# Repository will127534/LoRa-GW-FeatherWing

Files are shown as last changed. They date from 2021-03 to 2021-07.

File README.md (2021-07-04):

# LoRa Gateway FeatherWing

## Description
This is a LoRa Gateway board designed for FeatherWing ecosystem, based on Semtech SX1303 Digital Baseband Chip and Ublox EVA-7M GPS module. Board schematic is largely based on the SX1303 reference design, and this board is designed for 915Mhz operation.


**This Design is still in development process, please use with caution**  

**MCU software is also in development process**  
You can find it here https://github.com/will127534/SX1302_Arduino_Library

## FeatherWing Connection usage
SX1303 uses the SPI bus and two GPIO (CS and Reset on D5 and D6) on the FeatherWing to communicate with host MCU  
GPS module uses the UART pins and a GPIO for pulse-per-second output on A5.  

## Design Tool
KiCad v5.99 is used to design the board, and JLCPCB to manufactured the board.


I'm pretty noob about the KiCad stuff, so any feedback is welcome.

## Parts sourcing
I sourced most parts from Mouser, here is the parts list:
https://www.mouser.com/ProjectManager/ProjectDetail.aspx?AccessID=11549c8008

Note: SMA connector is not included, because it is related to the board thickness your are using, I'm using 1mm 4 layer pcb, and I can't find the connector on Mouser.

CC BY-SA 4.0

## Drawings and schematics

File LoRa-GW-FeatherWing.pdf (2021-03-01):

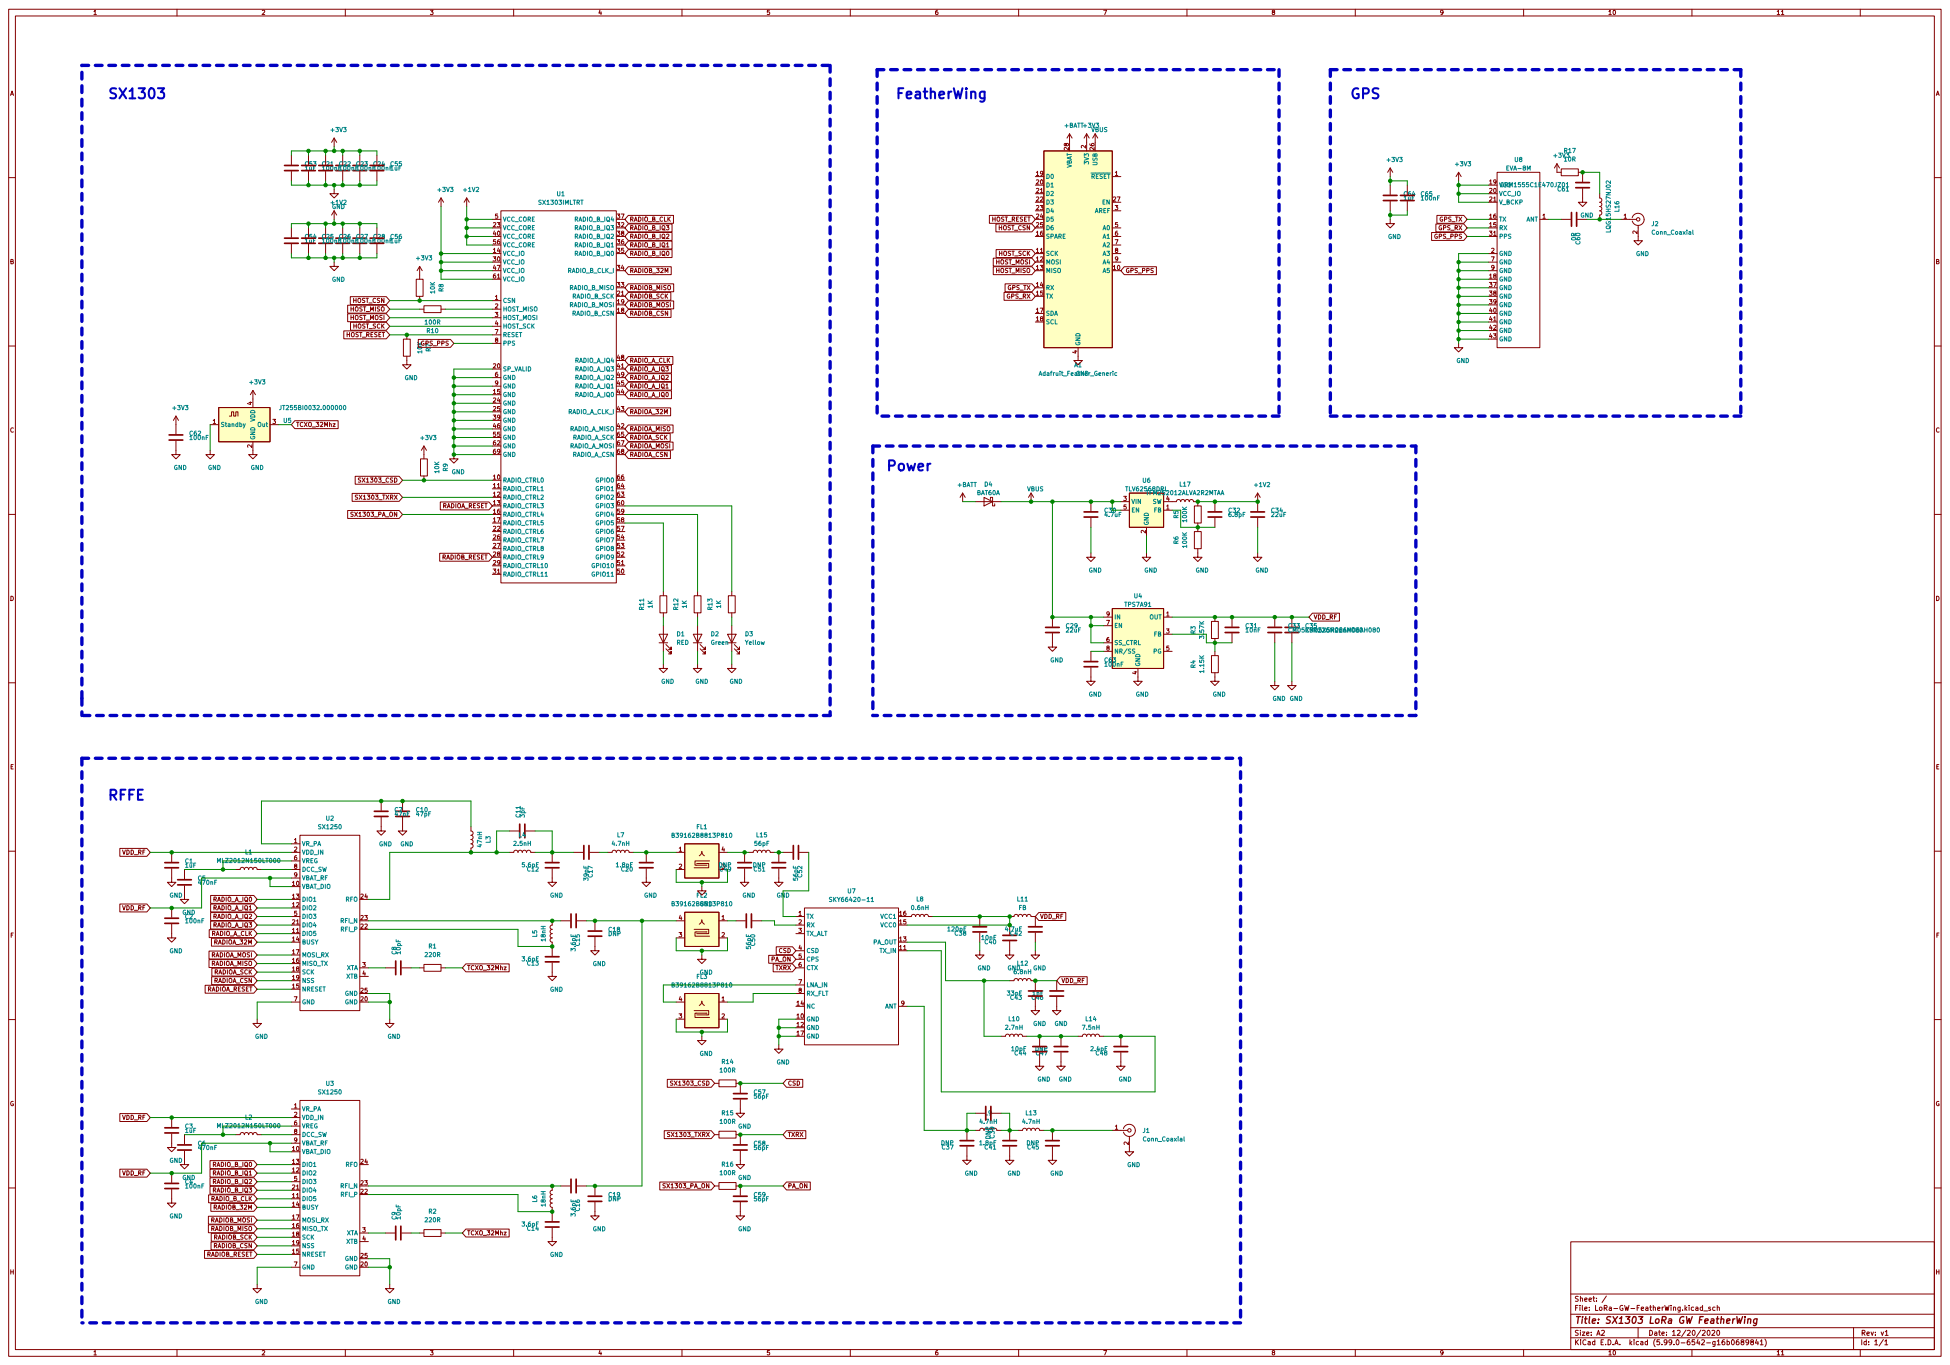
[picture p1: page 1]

2 D1 20 D2 21 D3 22 D4 23 D5 24 D6 25 USB 26 EN 27 VBAT 28 AREF 3 GND

File: LoRa-GW-FeatherWing.kicad_sch Sheet: /
Id: 1/1 Title: SX1303 LoRa GW FeatherWing

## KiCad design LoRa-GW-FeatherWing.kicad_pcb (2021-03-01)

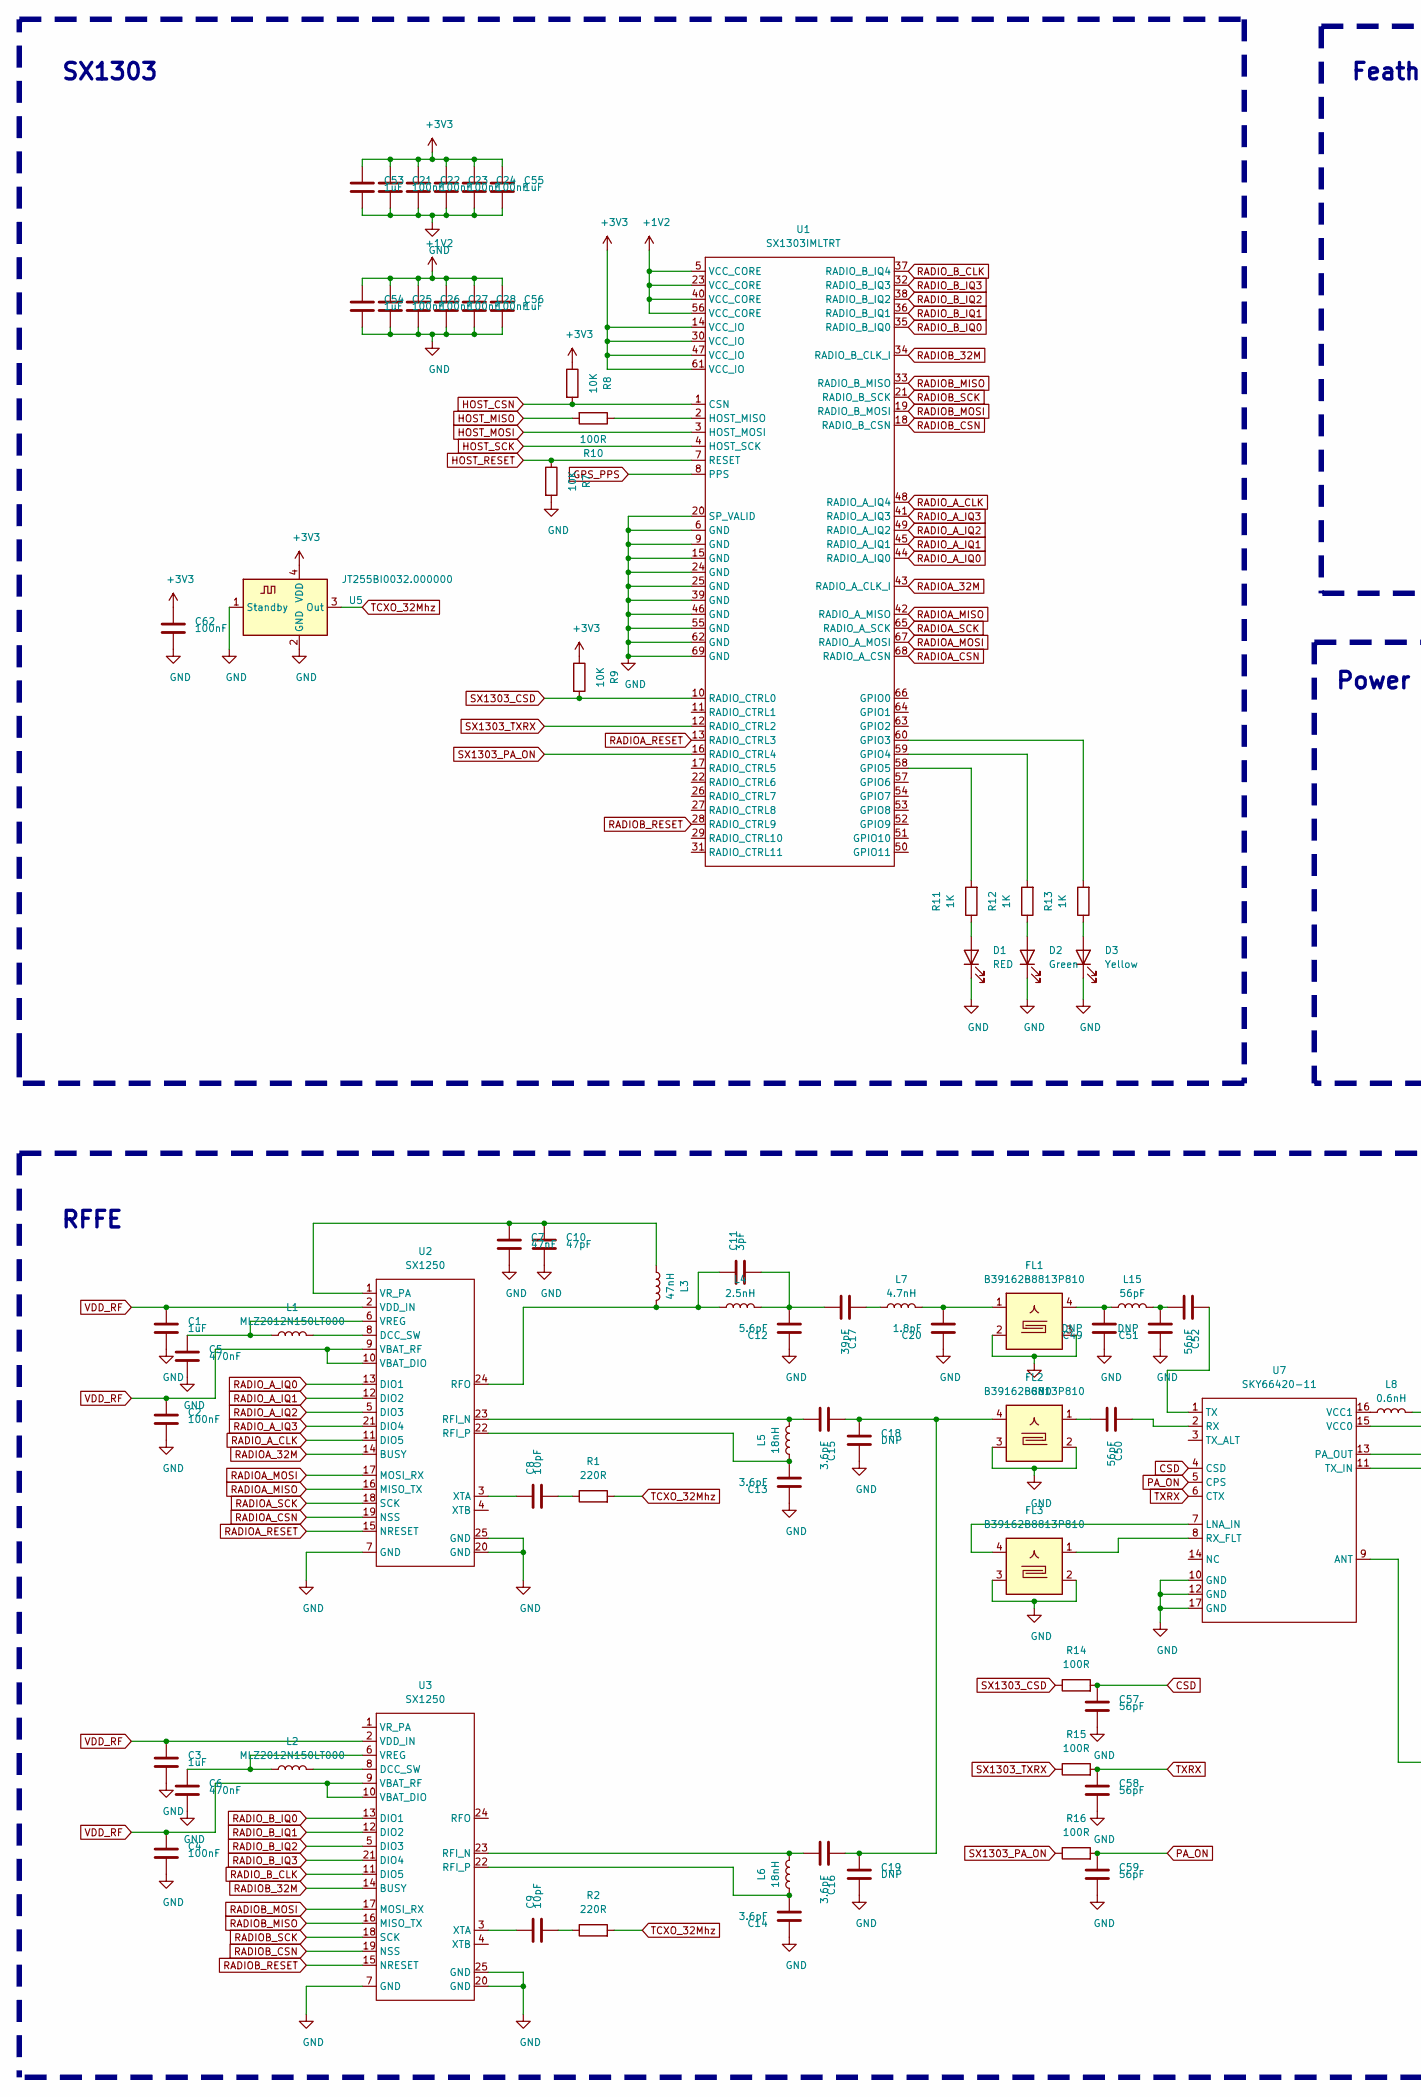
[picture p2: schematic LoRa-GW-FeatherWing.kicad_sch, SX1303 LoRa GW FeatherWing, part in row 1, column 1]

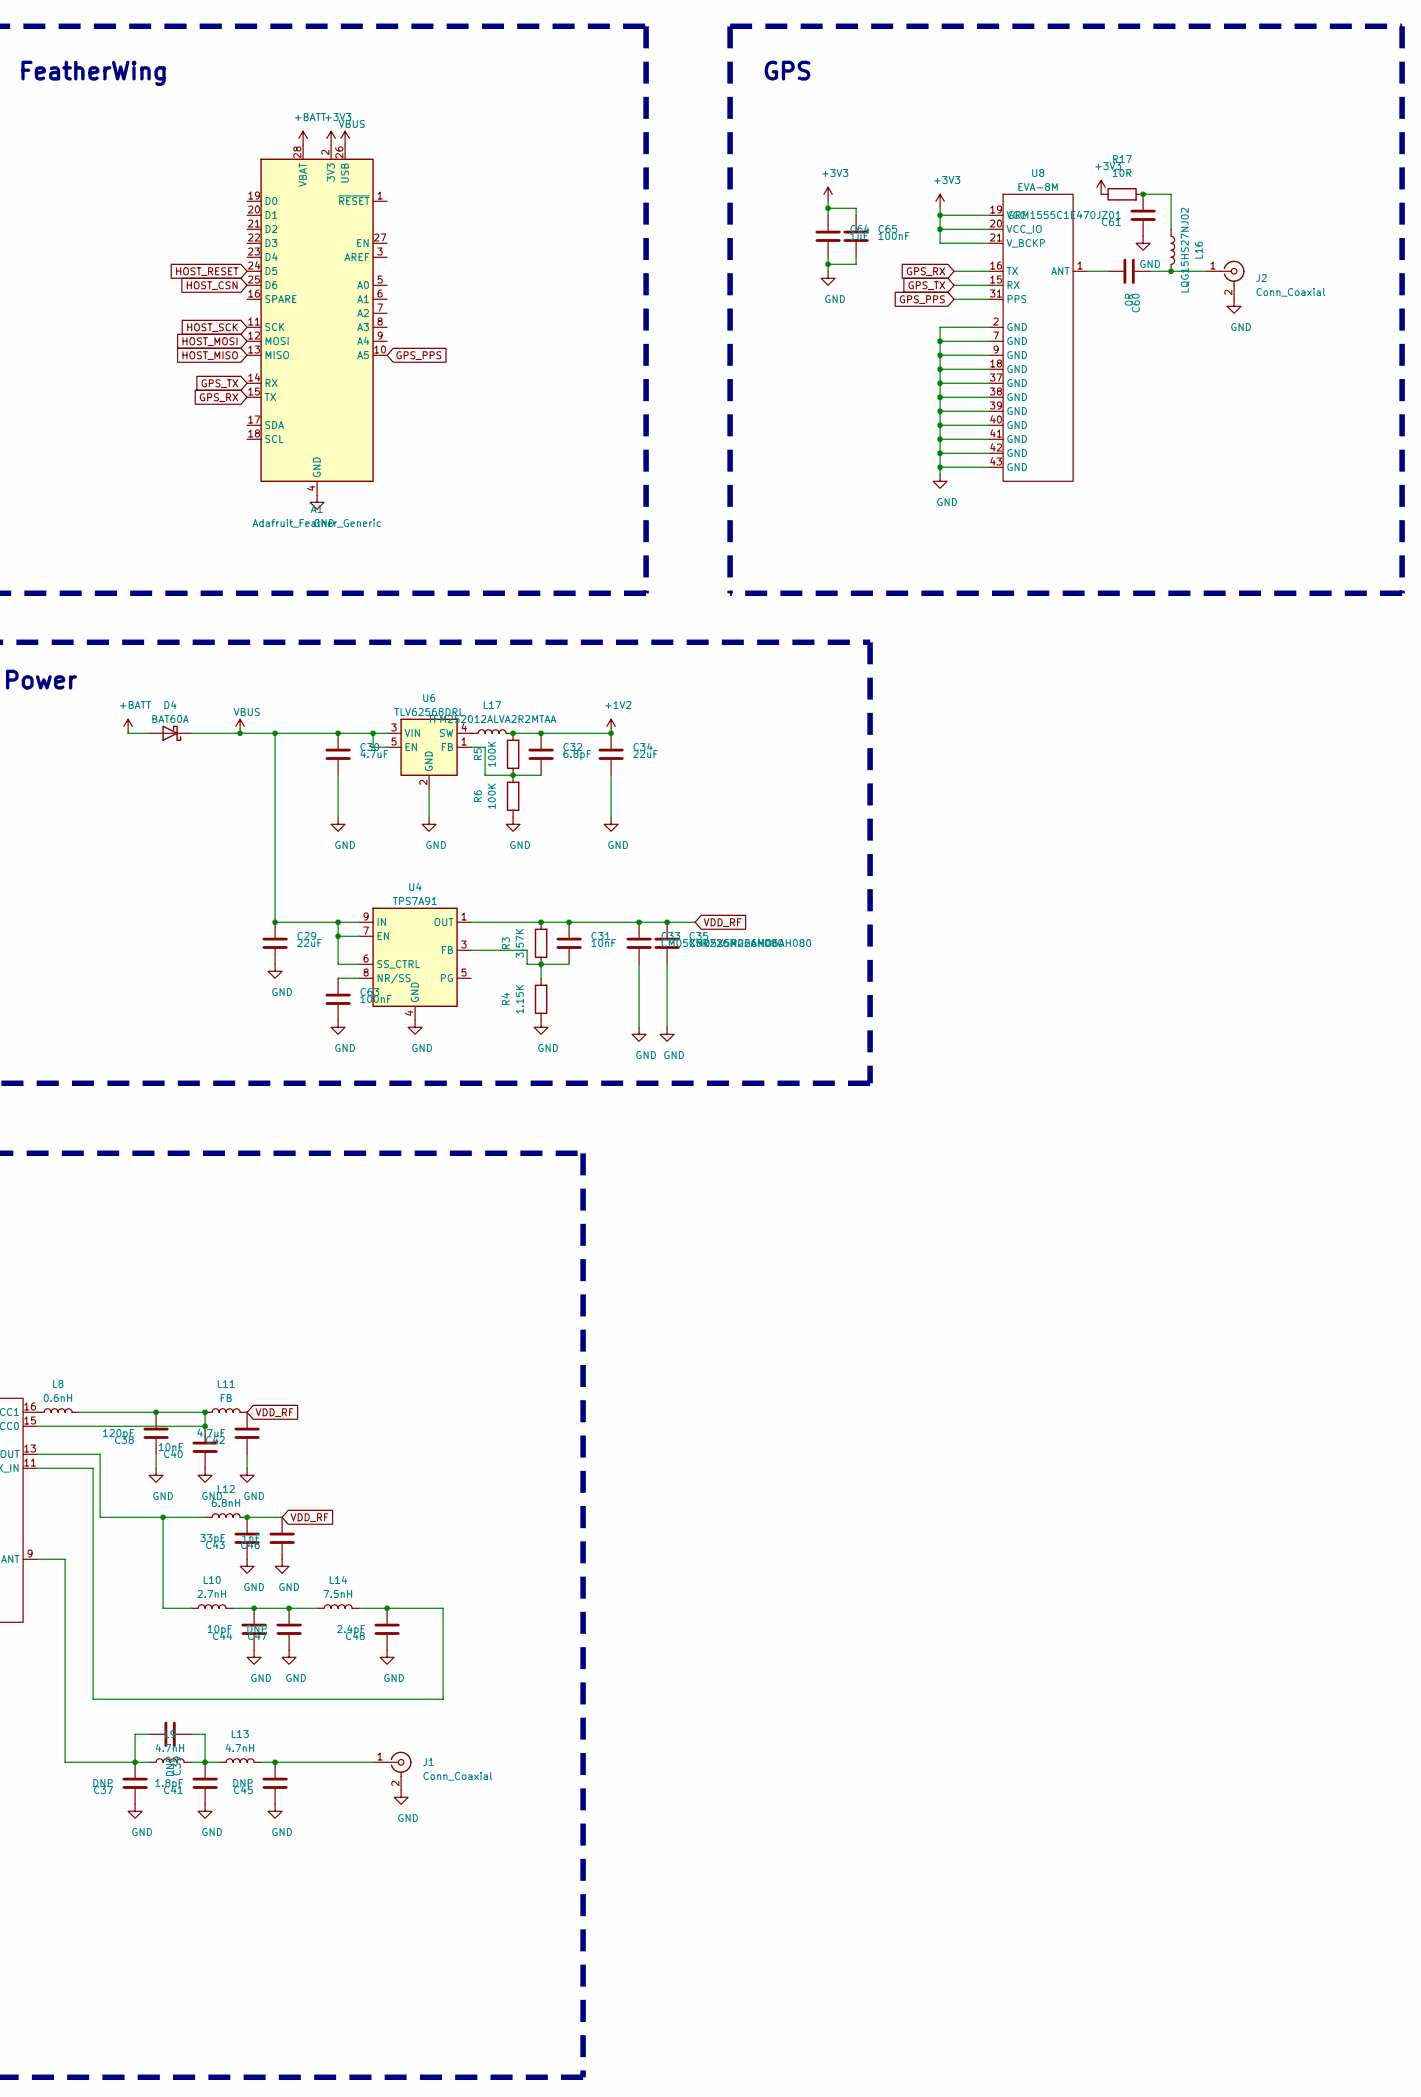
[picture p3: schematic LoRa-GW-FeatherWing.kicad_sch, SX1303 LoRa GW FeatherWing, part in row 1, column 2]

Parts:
A1: Adafruit_Feather_Generic; Adafruit_Feather
C1, C3, C64: 1uF; C_0402_1005Metric
C2, C4, C65: 100nF; C_0402_1005Metric
C5, C6: 470nF; C_0402_1005Metric
C7: 47nF; C_0402_1005Metric
C8, C9, C44: 10pF; C_0201_0603Metric
C10: 47pF; C_0402_1005Metric
C11: 3pF; C_0201_0603Metric
C12: 5.6pF; C_0201_0603Metric
C13, C14, C15, C16: 3.6pF; C_0201_0603Metric
C17: 39pF; C_0201_0603Metric
C18, C19, C37, C39, C45, C47, C49, C51: DNP; C_0201_0603Metric
C20, C41: 1.8pF; C_0201_0603Metric
C21, C22, C23, C24, C25, C26, C27, C28, C62, C63: 100nF; C_0201_0603Metric
C29: 22uF; C_0402_1005Metric
C30, C42: 4.7uF; C_0402_1005Metric
C31: 10nF; C_0402_1005Metric
C32: 6.8pF; C_0402_1005Metric
C33, C35: CM05X5R226M06AH080; C_0402_1005Metric
C34: 22uF; C_0603_1608Metric
C38: 120pF; C_0201_0603Metric
C40: 10nF; C_0201_0603Metric
C43: 33pF; C_0201_0603Metric
C46: 1nF; C_0201_0603Metric
C48: 2.4pF; C_0201_0603Metric
C50, C52, C57, C58, C59: 56pF; C_0201_0603Metric
C53, C54, C55, C56: 1uF; C_0201_0603Metric
C60: 0R; C_0201_0603Metric
C61: GRM1555C1E470JZ01; C_0201_0603Metric
D1: RED; LED_0603_1608Metric
D2: Green; LED_0603_1608Metric
D3: Yellow; LED_0603_1608Metric
D4: BAT60A; D_SOD-323
FL1, FL2, FL3: B39162B8813P810; Filter_1109-5_1.1x0.9mm
J1: Conn_Coaxial; SMA_Samtec_SMA-J-P-X-ST-EM1_EdgeMount
J2: Conn_Coaxial; U.FL_Hirose_U.FL-R-SMT-1_Vertical
L1, L2: MLZ2012N150LT000; L_0805_2012Metric
L3: 47nH; L_0201_0603Metric
L4: 2.5nH; L_0201_0603Metric
L5, L6: 18nH; L_0201_0603Metric
L7, L9, L13: 4.7nH; L_0201_0603Metric
L8: 0.6nH; L_0201_0603Metric
L10: 2.7nH; L_0201_0603Metric
L11: FB; L_0201_0603Metric
L12: 6.8nH; L_0201_0603Metric
L14: 7.5nH; L_0201_0603Metric
L15: 56pF; L_0201_0603Metric
L16: LQG15HS27NJ02; L_0201_0603Metric
L17: TFM252012ALVA2R2MTAA; L_1008_2520Metric
R1, R2: 220R; R_0201_0603Metric
R3: 3.57K; R_0402_1005Metric
R4: 1.15K; R_0402_1005Metric
R5, R6: 100K; R_0402_1005Metric
R7, R8, R9: 10K; R_0201_0603Metric
R10, R14, R15, R16: 100R; R_0201_0603Metric
R11, R12, R13: 1K; R_0402_1005Metric
R17: 10R; R_0402_1005Metric
U1: SX1303IMLTRT; SX1302IMLTRT
U2, U3: SX1250; HVQFN-24-1EP_4x4mm_P0.5mm_EP2.5x2.5mm
U4: TPS7A91; Texas_S-PDSO-N10_EP1.2x2mm
U5: JT255BI0032.000000; Oscillator_SMD_Abracon_ASDMB-4Pin_2.5x2.0mm
U6: TLV62568DRL; SOT-563
U7: SKY66420-11; QFN-16-1EP_3x3mm_P0.5mm_EP1.75x1.75mm
U8: EVA-8M

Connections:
+1V2: C25.1, C26.1, C27.1, C28.1, C32.1, C34.1, C54.1, C56.1, L17.2, R5.2, U1.5 (VCC_CORE), U1.23 (VCC_CORE), U1.40 (VCC_CORE), U1.56 (VCC_CORE)
+3V3: A1.2 (3V3), C21.1, C22.1, C23.1, C24.1, C53.1, C55.1, C62.1, C64.1, C65.1, R8.1, R9.1, R17.1, U1.14 (VCC_IO), U1.30 (VCC_IO), U1.47 (VCC_IO), U1.61 (VCC_IO), U5.4 (VDD), U8.19 (VCC), U8.20 (VCC_IO), U8.21 (V_BCKP)
+BATT: A1.28 (VBAT), D4.2 (A)
CSD: C57.1, R14.2, U7.4 (CSD)
GND: A1.4 (GND), C1.2, C2.2, C3.2, C4.2, C5.2, C6.2, C7.2, C10.2, C12.1, C13.1, C14.1, C18.2, C19.2, C20.1, C21.2, C22.2, C23.2, C24.2, C25.2, C26.2, C27.2, C28.2, C29.2, C30.2, C33.2, C34.2, C35.2, C37.1, C38.1, C40.1, C41.1, C42.1, C43.1, C44.1, C45.1, C46.1, C47.1, C48.1, C49.1, C51.1, C53.2, C54.2, C55.2, C56.2, C57.2, C58.2, C59.2, C61.1, C62.2, C63.2, C64.2, C65.2, D1.1 (K), D2.1 (K), D3.1 (K), FL1.2, FL1.3, FL1.5, FL2.2, FL2.3, FL2.5, FL3.2, FL3.3, FL3.5, J1.2 (Ext), J2.2 (Ext), R4.1, R6.1, R7.2, U1.6 (GND), U1.9 (GND), U1.15 (GND), U1.20 (SP_VALID), U1.24 (GND), U1.25 (GND), U1.39 (GND), U1.46 (GND), U1.55 (GND), U1.62 (GND), U1.69 (GND), U2.7 (GND), U2.20 (GND), U2.25 (GND), U3.7 (GND), U3.20 (GND), U3.25 (GND), U4.4 (GND), U4.11 (GND), U5.1 (Standby), U5.2 (GND), U6.2 (GND), U7.10 (GND), U7.12 (GND), U7.17 (GND), U8.2 (GND), U8.7 (GND), U8.9 (GND), U8.18 (GND), U8.37 (GND), U8.38 (GND), U8.39 (GND), U8.40 (GND), U8.41 (GND), U8.42 (GND), U8.43 (GND)
GPS_PPS: A1.10 (A5), U1.8 (PPS), U8.31 (PPS)
HOST_CSN: A1.25 (D6), R8.2, U1.1 (CSN)
HOST_MISO: A1.13 (MISO), R10.2
HOST_MOSI: A1.12 (MOSI), U1.3 (HOST_MOSI)
HOST_RESET: A1.24 (D5), R7.1, U1.7 (RESET)
HOST_SCK: A1.11 (SCK), U1.4 (HOST_SCK)
unnamed: C5.1, L1.1, U2.6 (VREG)
unnamed: C6.1, L2.1, U3.6 (VREG)
unnamed: C8.1, U2.3 (XTA)
unnamed: C8.2, R1.1
unnamed: C9.1, U3.3 (XTA)
unnamed: C9.2, R2.1
unnamed: C7.1, C10.1, L3.1, U2.1 (VR_PA)
unnamed: C11.1, L3.2, L4.1, U2.24 (RFO)
unnamed: C11.2, C12.2, C17.2, L4.2
unnamed: C13.2, L5.1, U2.22 (RFI_P)
unnamed: C14.2, L6.1, U3.22 (RFI_P)
unnamed: C15.1, C16.1, C18.1, C19.1, FL2.4
unnamed: C15.2, L5.2, U2.23 (RFI_N)
unnamed: C16.2, L6.2, U3.23 (RFI_N)
unnamed: C17.1, L7.1
unnamed: C20.2, FL1.1, L7.2
unnamed: C31.2, R3.1, R4.2, U4.3 (FB)
unnamed: C32.2, R5.1, R6.2, U6.1 (FB)
unnamed: C37.2, C39.2, L9.1, U7.9 (ANT)
unnamed: C38.2, C40.2, L8.2, L11.1, U7.15 (VCC0)
unnamed: C39.1, C41.2, L9.2, L13.1
unnamed: C44.2, C47.2, L10.2, L14.1
unnamed: C45.2, J1.1 (In), L13.2
unnamed: C48.2, L14.2, U7.11 (TX_IN)
unnamed: C49.2, FL1.4, L15.1
unnamed: C50.1, U7.2 (RX)
unnamed: C50.2, FL2.1
unnamed: C51.2, C52.2, L15.2
unnamed: C52.1, U7.1 (TX)
unnamed: C60.1, J2.1 (In), L16.2
unnamed: C60.2, U8.1 (ANT)
unnamed: C61.2, L16.1, R17.2
unnamed: C63.1, U4.8 (NR/SS)
unnamed: D1.2 (A), R11.1
unnamed: D2.2 (A), R12.1
unnamed: D3.2 (A), R13.1
unnamed: FL3.1, U7.8 (RX_FLT)
unnamed: FL3.4, U7.7 (LNA_IN)
unnamed: L1.2, U2.8 (DCC_SW)
unnamed: L2.2, U3.8 (DCC_SW)
unnamed: L8.1, U7.16 (VCC1)
unnamed: L10.1, L12.1, U7.13 (PA_OUT)
unnamed: L17.1, U6.4 (SW)
unnamed: R10.1, U1.2 (HOST_MISO)
unnamed: R11.2, U1.58 (GPIO5)
unnamed: R12.2, U1.59 (GPIO4)
unnamed: R13.2, U1.60 (GPIO3)
PA_ON: C59.1, R16.2, U7.5 (CPS)
RADIOA_32M: U1.43 (RADIO_A_CLK_I), U2.14 (BUSY)
RADIOA_CSN: U1.68 (RADIO_A_CSN), U2.19 (NSS)
RADIOA_MISO: U1.42 (RADIO_A_MISO), U2.16 (MISO_TX)
RADIOA_MOSI: U1.67 (RADIO_A_MOSI), U2.17 (MOSI_RX)
RADIOA_RESET: U1.13 (RADIO_CTRL3), U2.15 (NRESET)
RADIOA_SCK: U1.65 (RADIO_A_SCK), U2.18 (SCK)
RADIOB_32M: U1.34 (RADIO_B_CLK_I), U3.14 (BUSY)
RADIOB_CSN: U1.18 (RADIO_B_CSN), U3.19 (NSS)
RADIOB_MISO: U1.33 (RADIO_B_MISO), U3.16 (MISO_TX)
RADIOB_MOSI: U1.19 (RADIO_B_MOSI), U3.17 (MOSI_RX)
RADIOB_RESET: U1.28 (RADIO_CTRL9), U3.15 (NRESET)
RADIOB_SCK: U1.21 (RADIO_B_SCK), U3.18 (SCK)
RADIO_A_CLK: U1.48 (RADIO_A_IQ4), U2.11 (DIO5)
RADIO_A_IQ0: U1.44 (RADIO_A_IQ0), U2.13 (DIO1)
RADIO_A_IQ1: U1.45 (RADIO_A_IQ1), U2.12 (DIO2)
RADIO_A_IQ2: U1.49 (RADIO_A_IQ2), U2.5 (DIO3)
RADIO_A_IQ3: U1.41 (RADIO_A_IQ3), U2.21 (DIO4)
RADIO_B_CLK: U1.37 (RADIO_B_IQ4), U3.11 (DIO5)
RADIO_B_IQ0: U1.35 (RADIO_B_IQ0), U3.13 (DIO1)
RADIO_B_IQ1: U1.36 (RADIO_B_IQ1), U3.12 (DIO2)
RADIO_B_IQ2: U1.38 (RADIO_B_IQ2), U3.5 (DIO3)
RADIO_B_IQ3: U1.32 (RADIO_B_IQ3), U3.21 (DIO4)
SX1303_CSD: R9.2, R14.1, U1.10 (RADIO_CTRL0)
SX1303_PA_ON: R16.1, U1.16 (RADIO_CTRL4)
SX1303_TXRX: R15.1, U1.12 (RADIO_CTRL2)
TCXO_32Mhz: R1.2, R2.2, U5.3 (Out)
TXRX: C58.1, R15.2, U7.6 (CTX)
VBUS: A1.26 (USB), C29.1, C30.1, D4.1 (K), U4.6 (SS_CTRL), U4.7 (EN), U4.9 (IN), U4.10 (IN), U6.3 (VIN), U6.5 (EN)
VDD_RF: C1.1, C2.1, C3.1, C4.1, C31.1, C33.1, C35.1, C42.2, C43.2, C46.2, L11.2, L12.2, R3.2, U2.2 (VDD_IN), U2.9 (VBAT_RF), U2.10 (VBAT_DIO), U3.2 (VDD_IN), U3.9 (VBAT_RF), U3.10 (VBAT_DIO), U4.1 (OUT), U4.2 (OUT)

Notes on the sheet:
RFFE
SX1303
Power
FeatherWing
GPS

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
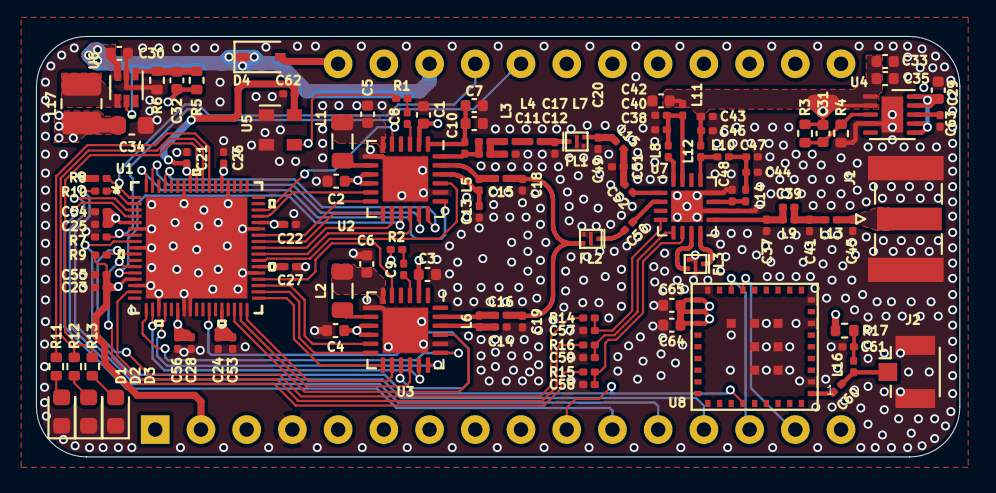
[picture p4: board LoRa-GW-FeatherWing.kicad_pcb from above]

Board: 4 copper layers, 51.3 x 23.4 mm, 116 parts (0 on the bottom side), 90 nets.

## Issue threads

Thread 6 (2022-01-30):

Understanding the RF FE

0y8w1x, 2022-01-30:
Hey, great project. I'm trying to build a LoRa gateway myself now. Can you please explain the FE architecture you use ?
I understand that the SKY66420 interfaces the antenna for both receiving and transmitting.

I don't understand the use of 2 SX1250. My guess would be that you can use both for receiving, so that would be 8x8 channels. And then sometimes you use 1 for transmitting ?

Also, I saw a picture on the forum, that you used an additional SX1262. That just adds to the confusion. What's the purpose of this transceiver in the chain ?

Appreciate your effort.

will127534, 2022-02-01:
You might want to take a look at SX1302 datasheet: [https://www.semtech.com/products/wireless-rf/lora-core/sx1302](https://www.semtech.com/products/wireless-rf/lora-core/sx1302) for the first half of your question.

The additional SX1262 is for Listen-Before-Talk Feature, basically act as channel activity scanning.

Closed 2022-02-01.

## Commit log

2021-03-01 Fixing GPS TX RX pin flipped issue
    [LoRa-GW-FeatherWing-B_Cu.gbl, LoRa-GW-FeatherWing-B_Mask.gbs, LoRa-GW-FeatherWing-B_Paste.gbp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]
2021-03-01 add dril file
    [LoRa-GW-FeatherWing-NPTH.drl, LoRa-GW-FeatherWing-PTH.drl]
2021-03-02 Updating Licence
    [LoRa-GW-FeatherWing.kicad_sch]
2021-03-02 Place drill file under gerber
    [LoRa-GW-FeatherWing-NPTH.drl, LoRa-GW-FeatherWing-PTH.drl]

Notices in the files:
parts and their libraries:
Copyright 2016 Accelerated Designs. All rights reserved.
